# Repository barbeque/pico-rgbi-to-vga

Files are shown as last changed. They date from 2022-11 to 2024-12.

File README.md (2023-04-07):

# Pico RGBI to VGA
_(Name subject to change in future)_

## Current Status
Not working

TODO:
 - [ ] Hook up logic analyzer example to capture input video
 - [ ] Buffer input video into output
 - [ ] Test 4-bit colour output mode
 - [ ] Create multiple palettes and palette switch handler

## The Problem
Several old computers, such as the NEC PC-6001mkII, use an "RGB+I" output at TTL level (+5V.) It is becoming difficult to locate monitors which support this output. Modern displays, and I use the term loosely because the VGA port has virtually become extinct as I am writing this in 2022, use analogue RGB to convey a greater range of colours.

For some computers, such as the NEC PC-8801mkII and Sanyo MBC-555, there are only three digital pins: red, green, and blue. Combined, this makes 8 colours (2<sup>3</sup> = 8.) Later computers added an "intensity" pin, which essentially works as the equivalent of a Shift key for these colours, and expands the available colours to 15 (2<sup>4</sup> = 16, but "bright black" is still just black.) For instance, the PC-6001mkII will signal "bright red" as by setting the "red" and "intensity" pins to 5V and everything else to 0V. "White" would set all four pins to 5V.

## Current Status
The board is still *IN DEVELOPMENT*. Please do not use it unless you are willing to test with your machines, potentially write some code, and submit bug reports and feedback. There may be a risk of damage to your hardware or to the Pico if things go wrong.

## Compatibility
Here is a brief list of computers that are known to work with such a model, although they may require a custom cable made for this board:

 | Computer | Adapter configuration | Notes |
 |----------|-----------------------|-------|
 | NEC PC-6001mkII | Intensity: pin 3 | Not tested |
 | NEC PC-6001mkIISR | Intensity: pin 3 | Not tested |
 | NEC PC-6601 | Intensity: pin 3 | Not tested |
 | NEC PC-6601SR | Intensity: pin 3 | Not tested |
 | NEC PC-9801UV | Disable intensity | Not tested |
 | NEC PC-8001 | Disable intensity | Not tested |
 | NEC PC-8801mkII | Intensity *must* be disabled or it will pass +12V through and *damage the Pico*! | Not tested |
 | IBM CGA | Custom cable required | Not tested |
 | Sanyo MBC-550/MBC-555 | Disable intensity | Not tested |
 | Commodore C128 | Custom cable required | Not tested |
 | Fujitsu FM-7/FM-New7 | Disable intensity | Not tested; intensity may not be possible |
 | Fujitsu FM-77AV2 | Custom cable required | Not tested; intensity may not be possible |

Please submit a pull request if you have tested another computer, know of one to add to the list, or can contribute custom cable designs.

## Build Instructions
### Hardware
TODO

### Software
Refer to [the `firmware` directory](firmware/)'s README for build instructions.

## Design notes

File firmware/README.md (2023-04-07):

# Firmware for Pico RGBI to VGA

## Build instructions
 * Install `cmake` and the Raspberry Pi Pico SDK and all related tools
    * Mac: https://www.robertthasjohn.com/post/how-to-set-up-the-raspberry-pi-pico-for-development-on-macos
 * Clone [PicoVGA source tree](https://github.com/Panda381/PicoVGA) and put it parallel to the `pico-rgbi-to-vga` checkout as `PicoVGA`, or set `PICOVGA_PATH` environment variable if you want to put it somewhere else
 * `cmake .` will generate a Makefile
 * `make` will use that Makefile to generate `rgbi.uf2`, if all went well
 * Hold the button down on the Pico as you plug it into the USB port, then drag `rgbi.uf2` onto the Pico to flash it.

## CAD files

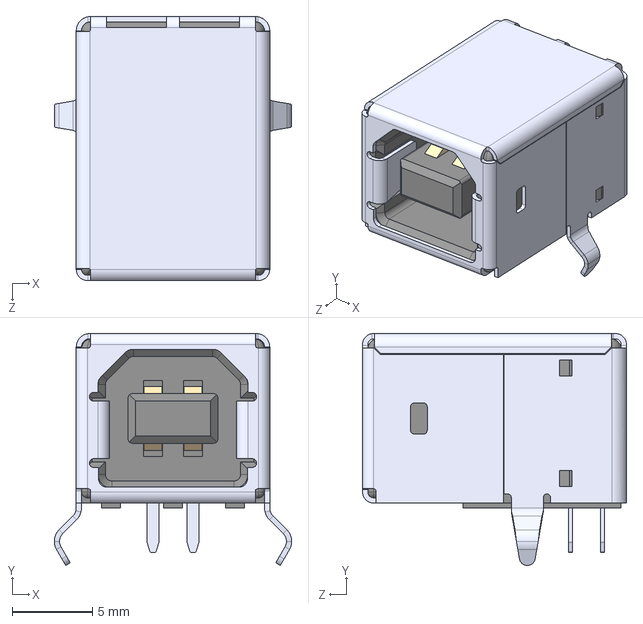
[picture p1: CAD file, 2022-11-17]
USB-B1HSB6/USB-B1HSB6.step
14.8 x 14.5 x 16.5 mm

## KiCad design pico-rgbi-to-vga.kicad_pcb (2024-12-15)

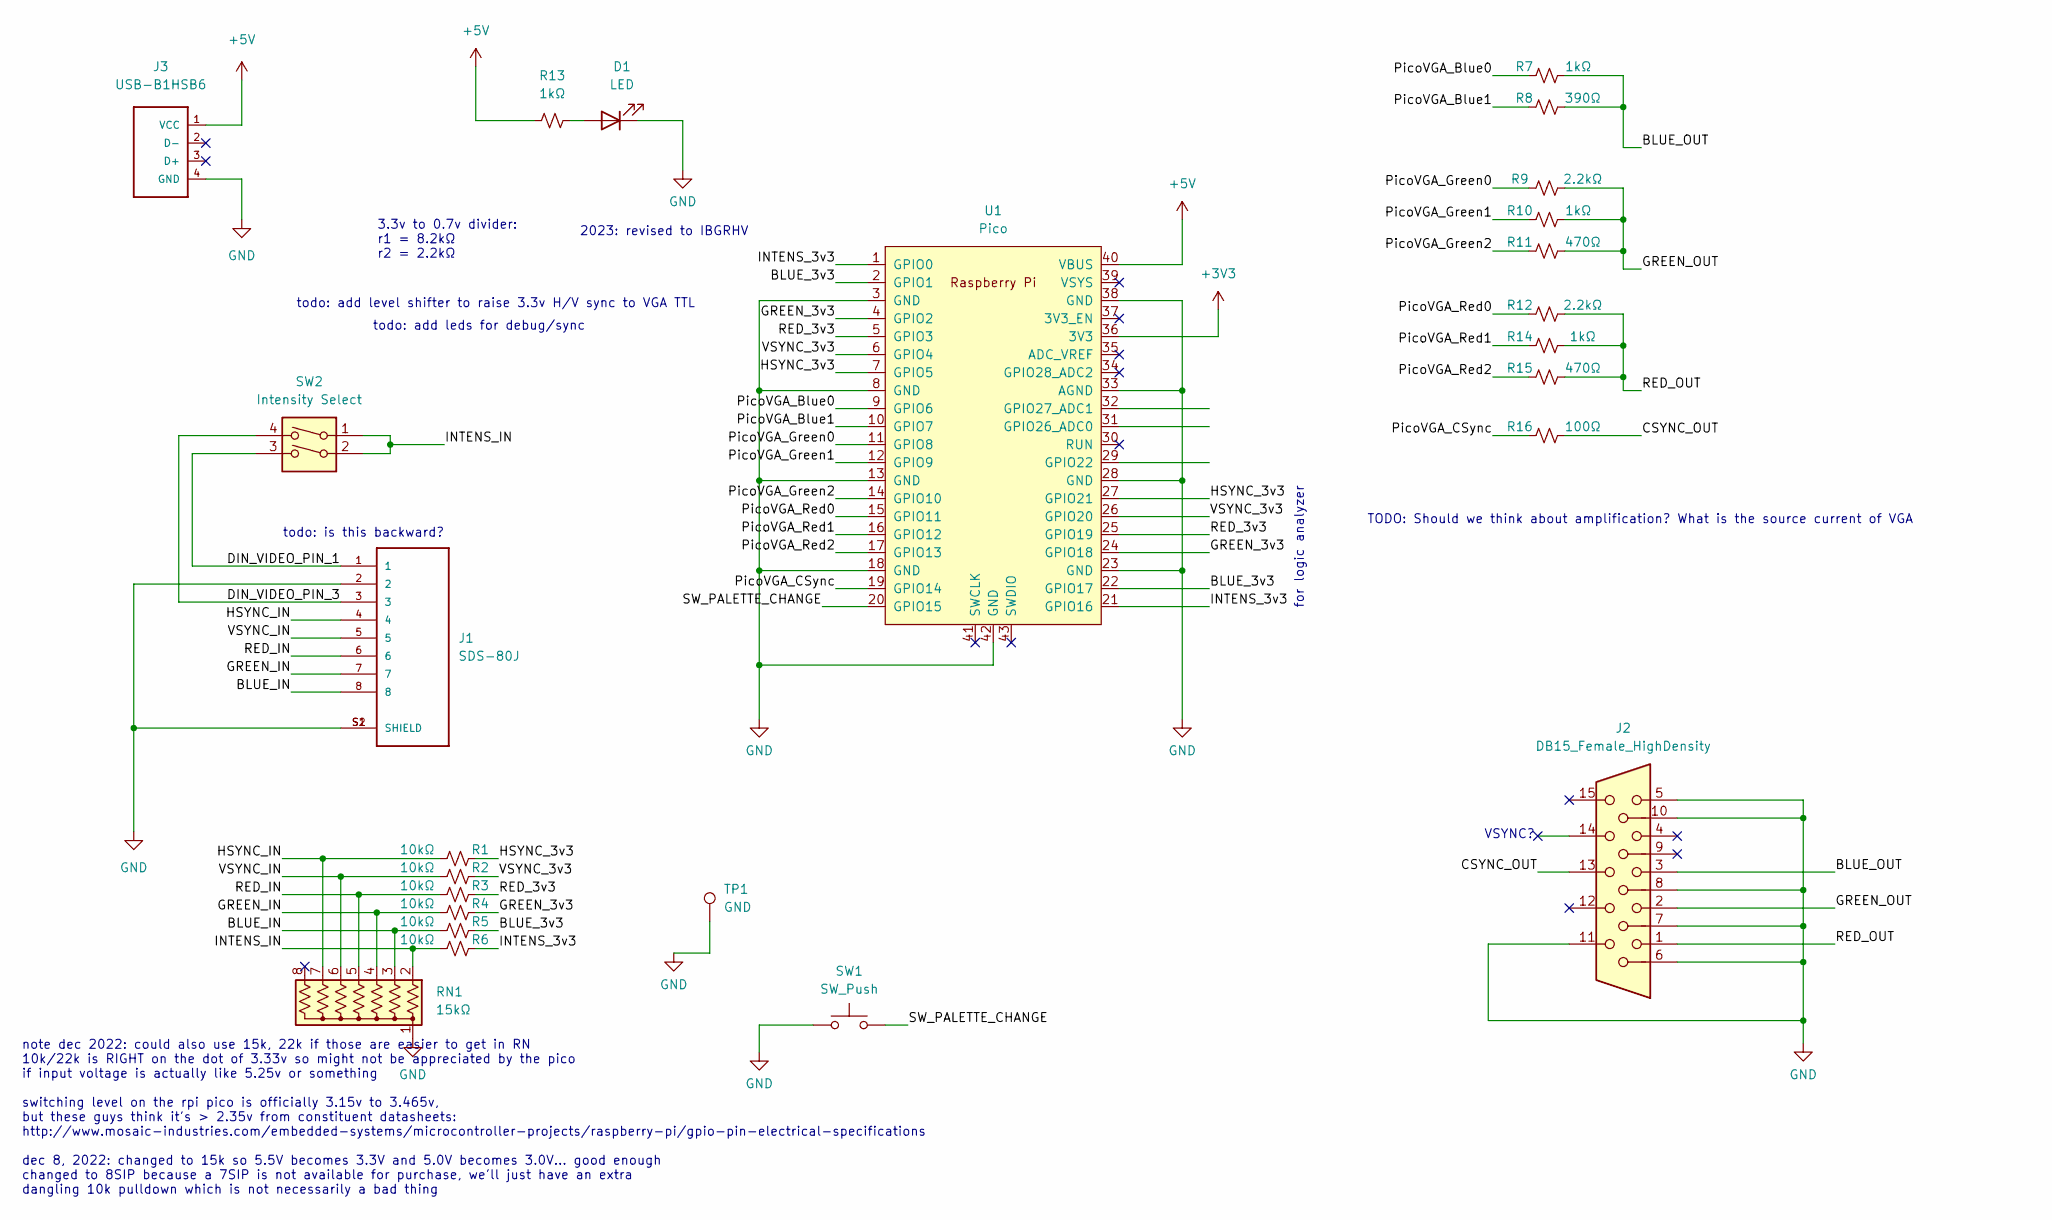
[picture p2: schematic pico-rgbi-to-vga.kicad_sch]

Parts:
D1: LED; LED_D3.0mm
J1: SDS-80J; CUI_SDS-80J
J2: DB15_Female_HighDensity; FIXED-1-1734530-1
J3: USB-B1HSB6; OST_USB-B1HSB6; DigiKey ED2983-ND
R1, R2, R3, R4, R5, R6: 10kΩ; R_0805_2012Metric_Pad1.20x1.40mm_HandSolder
R7, R10, R13, R14: 1kΩ; R_0805_2012Metric_Pad1.20x1.40mm_HandSolder
R8: 390Ω; R_0805_2012Metric_Pad1.20x1.40mm_HandSolder
R9, R12: 2.2kΩ; R_0805_2012Metric_Pad1.20x1.40mm_HandSolder
R11, R15: 470Ω; R_0805_2012Metric_Pad1.20x1.40mm_HandSolder
R16: 100Ω; R_0805_2012Metric_Pad1.20x1.40mm_HandSolder
RN1: 15kΩ; R_Array_SIP8
SW1: SW_Push; SW_PUSH_6mm
SW2: Intensity Select; SW_DIP_SPSTx02_Slide_6.7x6.64mm_W7.62mm_P2.54mm_LowProfile
TP1: GND; TestPoint_Loop_D2.54mm_Drill1.5mm_Beaded
U1: Pico; RPi_Pico_SMD_TH

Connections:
+3V3: U1.36 (3V3)
+5V: J3.1 (VCC), R13.1, U1.40 (VBUS)
/BLUE_3v3: R5.1, U1.2 (GPIO1), U1.22 (GPIO17)
/BLUE_IN: J1.8, R5.2, RN1.3 (R2)
/BLUE_OUT: J2.3, R7.2, R8.2
/CSYNC_OUT: J2.13, R16.2
/DIN_VIDEO_PIN_1: J1.1, SW2.3
/DIN_VIDEO_PIN_3: J1.3, SW2.4
/GREEN_3v3: R4.1, U1.4 (GPIO2), U1.24 (GPIO18)
/GREEN_IN: J1.7, R4.2, RN1.4 (R3)
/GREEN_OUT: J2.2, R9.2, R10.2, R11.2
/HSYNC_3v3: R1.1, U1.7 (GPIO5), U1.27 (GPIO21)
/HSYNC_IN: J1.4, R1.2, RN1.7 (R6)
/INTENS_3v3: R6.1, U1.1 (GPIO0), U1.21 (GPIO16)
/INTENS_IN: R6.2, RN1.2 (R1), SW2.1, SW2.2
/PicoVGA_Blue0: R7.1, U1.9 (GPIO6)
/PicoVGA_Blue1: R8.1, U1.10 (GPIO7)
/PicoVGA_CSync: R16.1, U1.19 (GPIO14)
/PicoVGA_Green0: R9.1, U1.11 (GPIO8)
/PicoVGA_Green1: R10.1, U1.12 (GPIO9)
/PicoVGA_Green2: R11.1, U1.14 (GPIO10)
/PicoVGA_Red0: R12.1, U1.15 (GPIO11)
/PicoVGA_Red1: R14.1, U1.16 (GPIO12)
/PicoVGA_Red2: R15.1, U1.17 (GPIO13)
/RED_3v3: R3.1, U1.5 (GPIO3), U1.25 (GPIO19)
/RED_IN: J1.6, R3.2, RN1.5 (R4)
/RED_OUT: J2.1, R12.2, R14.2, R15.2
/SW_PALETTE_CHANGE: SW1.2, U1.20 (GPIO15)
/VSYNC_3v3: R2.1, U1.6 (GPIO4), U1.26 (GPIO20)
/VSYNC_IN: J1.5, R2.2, RN1.6 (R5)
GND: D1.1 (K), J1.2, J1.S1 (SHIELD), J1.S2 (SHIELD), J2.5, J2.6, J2.7, J2.8, J2.10, J2.11, J3.4 (GND), RN1.1 (common), SW1.1, TP1.1, U1.3 (GND), U1.8 (GND), U1.13 (GND), U1.18 (GND), U1.23 (GND), U1.28 (GND), U1.33 (AGND), U1.38 (GND), U1.42 (GND)
unnamed: D1.2 (A), R13.2

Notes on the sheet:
TODO: Should we think about amplification? What is the source current of VGA
3.3v to 0.7v divider: r1 = 8.2kΩ r2 = 2.2kΩ
todo: is this backward?
2023: revised to IBGRHV
todo: add leds for debug/sync
VSYNC?
note dec 2022: could also use 15k, 22k if those are easier to get in RN 10k/22k is RIGHT on the dot of 3.33v so might not be appreciated by the pico if input voltage is actually like 5.25v or something switching level on the rpi pico is officially 3.15v to 3.465v, but these guys think it's > 2.35v 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
todo: add level shifter to raise 3.3v H/V sync to VGA TTL
for logic analyzer

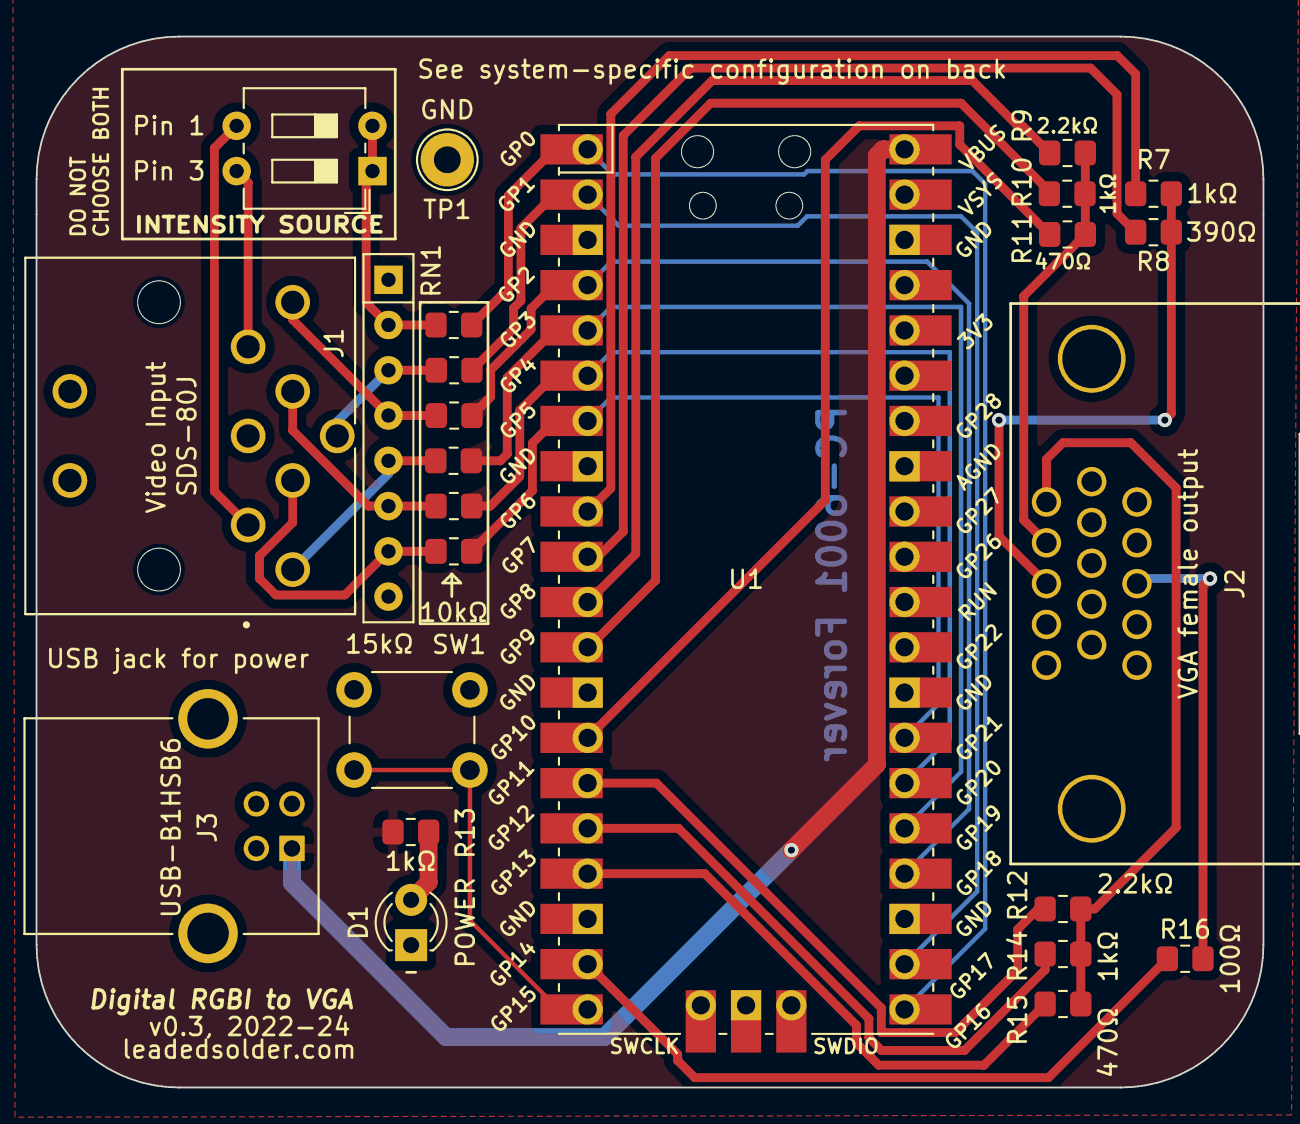
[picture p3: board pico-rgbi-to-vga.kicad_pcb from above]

Board: 2 copper layers, 68.8 x 59.0 mm, 25 parts (0 on the bottom side), 31 nets.

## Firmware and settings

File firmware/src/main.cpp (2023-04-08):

// ****************************************************************************
//
//                                 Main code
//
// ****************************************************************************

#include "include.h"

// Draw box
u8 Box[WIDTHBYTE*HEIGHT] __attribute__ ((aligned(4)));

void SketchyDraw() {
	u8* dest = &Box[0];
	int red = 0;
	int green = 0;
	int blue = 0;
	// Just a demo program to see if I can figure out
	// how to draw to a frame buffer

	for(int y = HEIGHT - 1; y >= 0; --y) {
		for(int x = 0; x < WIDTH; ++x) {
			if(y < 5 || y > HEIGHT - 5 || x < 5 || x > WIDTH - 5) {
				red = green = blue = 255;
			}
			else {
				red = 0;
				green = 0;
				blue = 0;
			}

			*dest++ = (u8)((red & 0xe0) | ((green & 0xe0) >> 3) | (blue >> 6));
		}
	}
}

int main()
{
	// Set up input PIO.

	// Input basic loop:
	//	start capturing at vsync (+timing?)
	//	start new line at hsync (+timing?)
	//	loop at some fixed frequency to capture four pins (IBGR) 320 times
	//	transfer those pins into the video buffer somehow?

	// I have 66ms per line, so that means I need to sample one pixel every 0.2ish ms or 0.005MHz?

	// Might need to set sm_config_set_clkdiv to slow the input SM clock relative to the VGA one

	// It may have been a mistake to put intensity before HV RGB as PIO `in` captures a block at a time.
	// Might want to bodge the hardware so it goes I, B, G, R, V, H even if it's more annoying to
	// route - that way we can just grip and rip the first four pins

	// run VGA core
	// initialize videomode

	// RES_EGA - 528x400 (really 512x400, it seems)
	// RES_VGA - 640x480
	// RES_CGA - 320x200

	// TODO: 4-bit colour
	// TODO: palette configuration

	Video(DEV_VGA, RES_CGA, FORM_8BIT, Box);

	SketchyDraw();

	// main loop
	while (true)
	{
		// Reformat and copy from the DMA recipient raw data buffer
		// (it chunks out 32-bits at a time)
	}
}

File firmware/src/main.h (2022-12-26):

// ****************************************************************************
//
//                                 Main code
//
// ****************************************************************************

#ifndef _MAIN_H
#define _MAIN_H

// Input RGBI pins
#define PIN_INPUT_RED       5
#define PIN_INPUT_GREEN     4
#define PIN_INPUT_BLUE      3
#define PIN_INPUT_INTENS    0
#define PIN_INPUT_HSYNC     2
#define PIN_INPUT_VSYNC     1

#define INPUT_FIRST_PIN     0
#define INPUT_PIN_COUNT     6

// Output screen resolution
#define WIDTH	320	// screen width
#define HEIGHT	200	// screen height
#define WIDTHBYTE WIDTH	// bytes per line

// Draw box
extern u8 Box[WIDTHBYTE*HEIGHT] __attribute__ ((aligned(4)));

#endif // _MAIN_H

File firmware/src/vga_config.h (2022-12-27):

// ****************************************************************************
//                                 
//                            VGA configuration
//
// ****************************************************************************

// === Configuration
#define LAYERS		1	// total layers 1..4 (1 base layer + 3 overlapped layers)
#define SEGMAX		8	// max. number of video segment per video strip (size of 1 sSegm = 28 bytes)
#define STRIPMAX	8	// max. number of video strips (size of 1 sStrip = sSegm size*SEGMAX+4 = 228 bytes)
				// size of sScreen = sStrip size*STRIPMAX+4 = 1828 bytes

#define MAXX		640	// max. resolution in X direction (must be power of 4)
#define MAXY		480	// max. resolution in Y direction

#define MAXLINE		700	// max. number of scanlines (including sync and dark lines)

// === Scanline render buffers (800 pixels: default size of buffers = 2*4*(800+8+800+24)+800 = 13856 bytes
//    Requirements by format, base layer 0, 1 wrap X segment:
//	GF_GRAPH8 ... control buffer 16 bytes
//	GF_TILE8 ... control buffer "width"+8 bytes
//	GF_TILE16 ... control buffer "width/2"+8 bytes
//	GF_TILE32 ... control buffer "width/4"+8 bytes
//	GF_TILE64 ... control buffer "width/8"+8 bytes
//	GF_PROGRESS ... control buffer 24 bytes
//	other formats: data buffer "width" bytes, control buffer 16 bytes
#define DBUF0_MAX	(MAXX+8)	// max. size of data buffer of layer 0
#define CBUF0_MAX	((MAXX+24)/4)	// max. size of control buffer of layer 0

//    Requirements by format, overlapped layer 1..3:
//	LAYERMODE_SPRITE* ... data buffer "width"+4 bytes, control buffer 24 bytes
//	LAYERMODE_FASTSPRITE* ... data buffer "width"+4 bytes, control buffer up to "width*2"+16 bytes
//	other formats ... data buffer 4 bytes, control buffer 24 bytes
#define DBUF1_MAX	(MAXX+8)	// max. size of data buffer of layer 1
#define CBUF1_MAX	((MAXX+24)/4)	// max. size of control buffer of layer 1

#define DBUF2_MAX	(MAXX+8)	// max. size of data buffer of layer 2
#define CBUF2_MAX	((MAXX+24)/4)	// max. size of control buffer of layer 2

#define DBUF3_MAX	(MAXX+8)	// max. size of data buffer of layer 3
#define CBUF3_MAX	((MAXX+24)/4)	// max. size of control buffer of layer 3

#if LAYERS==1
#define	DBUF_MAX	DBUF0_MAX	// max. size of data buffer
#define	CBUF_MAX	CBUF0_MAX	// max. size of control buffer
#elif LAYERS==2
#define	DBUF_MAX	(DBUF0_MAX+DBUF1_MAX)	// max. size of data buffer
#define	CBUF_MAX	(CBUF0_MAX+CBUF1_MAX)	// max. size of control buffer
#elif LAYERS==3
#define	DBUF_MAX	(DBUF0_MAX+DBUF1_MAX+DBUF2_MAX)	// max. size of data buffer
#define	CBUF_MAX	(CBUF0_MAX+CBUF1_MAX+CBUF2_MAX)	// max. size of control buffer
#elif LAYERS==4
#define	DBUF_MAX	(DBUF0_MAX+DBUF1_MAX+DBUF2_MAX+DBUF3_MAX) // max. size of data buffer
#define	CBUF_MAX	(CBUF0_MAX+CBUF1_MAX+CBUF2_MAX+CBUF3_MAX) // max. size of control buffer
#else
#error Unsupported number of layers!
#endif

// === VGA port pins
//	GP0 ... VGA B0 blue
//	GP1 ... VGA B1
//	GP2 ... VGA G0 green
//	GP3 ... VGA G1
//	GP4 ... VGA G2
//	GP5 ... VGA R0 red
//	GP6 ... VGA R1
//	GP7 ... VGA R2
//	GP8 ... VGA SYNC synchronization (inverted: negative SYNC=LOW=0x80, BLACK=HIGH=0x00)
#define VGA_GPIO_FIRST	6	// first VGA GPIO
#define VGA_GPIO_NUM	9	// number of VGA GPIOs, including HSYNC and VSYNC
#define VGA_GPIO_OUTNUM	8	// number of VGA color GPIOs, without HSYNC and VSYNC
#define VGA_GPIO_LAST	(VGA_GPIO_FIRST+VGA_GPIO_NUM-1)	// last VGA GPIO
#define VGA_GPIO_SYNC	14// VGA SYNC GPIO

// VGA PIO and state machines
#define VGA_PIO		pio0	// VGA PIO
#define VGA_SM0		0	// VGA state machine of base layer 0
#define VGA_SM1		1	// VGA state machine of overlapped layer 1
#define VGA_SM2		2	// VGA state machine of overlapped layer 2
#define VGA_SM3		3	// VGA state machine of overlapped layer 3
#define VGA_SM(layer)	(VGA_SM0+(layer)) // VGA state machine of the layer

#if LAYERS==1
#define VGA_SMALL	B0	// mask of all state machines
#elif LAYERS==2
#define VGA_SMALL	(B0+B1) // mask of all state machines
#elif LAYERS==3
#define VGA_SMALL	(B0+B1+B2) // mask of all state machines
#elif LAYERS==4
#define VGA_SMALL	(B0+B1+B2+B3) // mask of all state machines
#else
#error Unsupported number of layers!
#endif

// VGA DMA
#define VGA_DMA		0		// VGA DMA base channel
#define VGA_DMA_CB0	(VGA_DMA+0)	// VGA DMA channel - control block of base layer
#define VGA_DMA_PIO0	(VGA_DMA+1)	// VGA DMA channel - copy data of base layer to PIO (raises IRQ0 on quiet)
#define VGA_DMA_CB1	(VGA_DMA+2)	// VGA DMA channel - control block of overlapped layer 1
#define VGA_DMA_PIO1	(VGA_DMA+3)	// VGA DMA channel - copy data of overlapped layer 1 to PIO
#define VGA_DMA_CB2	(VGA_DMA+4)	// VGA DMA channel - control block of overlapped layer 1
#define VGA_DMA_PIO2	(VGA_DMA+5)	// VGA DMA channel - copy data of overlapped layer 2 to PIO
#define VGA_DMA_CB3	(VGA_DMA+6)	// VGA DMA channel - control block of overlapped layer 1
#define VGA_DMA_PIO3	(VGA_DMA+7)	// VGA DMA channel - copy data of overlapped layer 3 to PIO
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

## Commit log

2022-11-05 Sketchy rough-out
    [pico-rgbi-to-vga.kicad_pcb, pico-rgbi-to-vga.kicad_sch]
2022-11-05 Ground plane, bigger board
    [pico-rgbi-to-vga.kicad_pcb, pico-rgbi-to-vga.kicad_sch]
2022-11-17 Basic left-side implementation with voltage divider
    [USB-B1HSB6.step, pico-rgbi-to-vga.kicad_pcb, pico-rgbi-to-vga.kicad_sch]
2022-11-17 Power LED, output voltage divider
    [pico-rgbi-to-vga.kicad_pcb, pico-rgbi-to-vga.kicad_sch]
2022-11-17 Power plane
    [pico-rgbi-to-vga.kicad_pcb]
2022-11-17 Fully laid out, I think
    [pico-rgbi-to-vga.kicad_pcb, pico-rgbi-to-vga.kicad_sch]
2022-11-17 Palette toggle button
    [pico-rgbi-to-vga.kicad_pcb, pico-rgbi-to-vga.kicad_sch]
2022-11-17 V0.1 sent to Fab
    [pico-rgbi-to-vga.kicad_pcb]
2022-11-17 Use PicoVGA resistor ladder
    [pico-rgbi-to-vga.kicad_pcb, pico-rgbi-to-vga.kicad_sch]
2022-12-07 Change divider values
    [pico-rgbi-to-vga.kicad_sch]
2022-12-07 Fix label
    [pico-rgbi-to-vga.kicad_pcb]
2022-12-07 Use 8SIP for Vdiv pulldown, 7SIP is not available
    [pico-rgbi-to-vga.kicad_pcb, pico-rgbi-to-vga.kicad_sch]
2022-12-11 Fix VGA output pins to use GPIOs that exist
    [pico-rgbi-to-vga.kicad_pcb, pico-rgbi-to-vga.kicad_sch]
2022-12-12 Set up firmware in repository from PicoVGA example, but use cmake (#1)
    * Source from raytracer
    * A wordy CMake file
    * A successful build
    * README in case I come back to this later
    * Change the sky colour
    * Remove generated files
2023-04-07 Link to Mac RPi Pico setup
2023-04-08 KiCad7; reorder pins so HV won't get captured
    [pico-rgbi-to-vga.kicad_pcb, pico-rgbi-to-vga.kicad_sch]
2023-05-23 Rewired to be IBGRHV
    [pico-rgbi-to-vga.kicad_pcb, pico-rgbi-to-vga.kicad_sch]
2023-12-18 Doubts about DIN8 pinout
    [pico-rgbi-to-vga.kicad_pcb, pico-rgbi-to-vga.kicad_sch]
2024-06-03 Set heights for turbocase
    [pico-rgbi-to-vga.kicad_pcb, pico-rgbi-to-vga.kicad_sch]
2024-12-04 Update to kicad 8
    [pico-rgbi-to-vga.kicad_pcb, pico-rgbi-to-vga.kicad_sch]
2024-12-13 Some captures from the Pico
2024-12-13 Fix boneheaded pinout mixup
    [pico-rgbi-to-vga.kicad_pcb, pico-rgbi-to-vga.kicad_sch]
2024-12-15 V0.3 prep, adding logic analyzer lines
    [pico-rgbi-to-vga.kicad_pcb, pico-rgbi-to-vga.kicad_sch]
2024-12-15 Plot v0.3
    [pico-rgbi-to-vga.kicad_pcb]

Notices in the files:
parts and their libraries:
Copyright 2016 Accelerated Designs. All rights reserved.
